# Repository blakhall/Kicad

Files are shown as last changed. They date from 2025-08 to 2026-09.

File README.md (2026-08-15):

# 📝 사내 KiCad 공통 라이브러리 관리 규정 (README)

본 문서는 사내 KiCad(키캐드) 심볼, 풋프린트, 3D 모델 라이브러리의 분류 체계를 표준화하고, 다른 부서 및 외부 참조 라이브러리와 유기적으로 동기화하여 관리하기 위한 표준 규정입니다.

---

## 1. 외부 참조 라이브러리 연동 및 유기적 관리 규정

사내 하드웨어 설계의 통일성과 검증된 회로 자산의 재사용을 위해, 아래의 외부 프로젝트 참조 폴더 내 파일과 이 저장소를 유기적으로 연동하여 관리합니다.

* **연동 및 참조 대상 폴더 경로:**  
  `D:\huni\sw\antigravity\k_dms\storage\archive\Projects\PMO\03_Ref\KiCad`
* **유기적 연동 및 관리 원칙:**
  1. **환경 변수 준수 (`KICAD_GITHUB`):**  
     참조 폴더의 가이드 문서(`KiCad_환경변수_경로설정_가이드.md`)에 따라, 프로젝트 내부 경로 지정 시 특정 개인의 절대 경로 대신 환경 변수 **`${KICAD_GITHUB}`**를 사용하여 치환합니다.
     * 모든 팀원은 본인의 KiCad 경로 구성(Configure Paths)에서 `KICAD_GITHUB` 변수명에 로컬 저장소 경로(`D:\huni\data\github\Kicad`)를 정확히 매핑하여 사용해야 합니다.
  2. **검증 자산의 동기화:**  
     `k_dms` 내의 PMO 관련 검증용 공통 라이브러리 자산에 업데이트가 발생할 경우, 이 저장소의 공통(`common`) 및 범용(`_gen`) 라이브러리에도 즉시 동기화하여 버전의 일관성을 유지합니다.
  3. **회로도 및 풋프린트 경로 치환 규칙:**  
     프로젝트 라이브러리 테이블(`sym-lib-table`, `fp-lib-table`) 등록 시, 환경 변수를 활용하여 아래 예시와 같이 유기적인 상대 경로 매핑을 구현합니다.
     * *올바른 예 (환경 변수 치환):* `(uri "${KICAD_GITHUB}/symbols/common_gen.kicad_sym")`
     * *잘못된 예 (절대 경로 사용 금지):* `(uri "D:/huni/data/github/Kicad/symbols/common_gen.kicad_sym")`

---

## 2. 라이브러리 분류 및 명명 표준 (Library Grouping Rules)

심볼(`symbols/`) 및 풋프린트(`footprints/`) 라이브러리는 무분별한 파일 생성을 방지하고 탐색 효율성을 극대화하기 위해 다음 규칙에 따라 관리합니다.

1. **공통 기본 소자 (`common` 계열):**
   * 저항(R), 콘덴서(C), 인덕터(L), 다이오드, GND 등 모든 보드에서 기본적으로 재사용되는 패시브 및 전원 기본 기호는 `common.kicad_sym` 및 `common.pretty`에만 수록합니다.
2. **기능별 범용 IC 및 소자 (`*_gen` 계열):**
   * 특정 단일 부품이 아니며 광범위하게 쓰이는 기능별 액티브 칩셋들은 접미사 `_gen`이 붙은 카테고리 파일에 병합하여 관리합니다.
   * *예시:* `mcu_gen.kicad_sym` (범용 MCU), `power_gen.kicad_sym` (범용 전원 IC 및 MOSFET), `common_gen.kicad_sym` (범용 아날로그/기초 IC)
3. **단독 부품 라이브러리 파일 생성 지양:**
   * 특정 단일 칩을 위한 개별 라이브러리 파일(예: `CSD17308.kicad_sym` 등)은 무분별한 파일 개수 증가를 유발하므로 원칙적으로 생성을 금지합니다.
   * 단, 핀 수가 100개 이상이거나 구조가 매우 독특한 대형 파워 모듈이나 특정 통신 모듈 등의 특수 부품에 한해서만 독자적인 명명을 예외 허용합니다.

---

---

## 3. 심볼 파라메터 필드 규정 (Symbol Property Fields Rule)

모든 부품 심볼에는 회로도 설계 완료 후 BOM(Bill of Materials) 추출 및 자재 매칭을 위해 아래의 **표준 파라메터 속성 필드**를 필수로 추가해야 합니다.

1. **`Reference` (참조 지정자):**  
   * 부품 카테고리에 맞는 영문 지시자 (예: IC는 `U`, 저항은 `R`, 콘덴서는 `C` 등). 심볼 상단에 표시 (글자 크기 1.27mm).
2. **`Value` (부품 값 / 모델명):**  
   * 실제 부품의 핵심 값 또는 세부 모델명 (예: `10k`, `0.1uF`, `MCP2122T-E/SN`). 심볼 하단에 표시 (글자 크기 1.27mm).
3. **`Footprint` (풋프린트):**  
   * 해당 부품의 PCB 패드 패턴 경로. 필수 지정하되 회로도상에서는 **숨김(Hide)** 처리.
4. **`Datasheet` (데이터시트):**  
   * 해당 부품의 제조사 공식 데이터시트 웹 링크. 필수 지정하되 **숨김(Hide)** 처리.
5. **`Description` (사양 설명):**  
   * 부품의 간략한 기능 및 사양 텍스트. **숨김(Hide)** 처리.
6. **`Manufacturer` (제조업체) [사내 필수]:**  
   * 부품의 공식 제조사 이름 (예: `Microchip Technology`, `Vishay`, `TI` 등). **숨김(Hide)** 처리.
7. **`PartNumber` (제조사 부품 번호 / MPN) [사내 필수]:**  
   * 주문 및 구매를 위한 공식 제조업체 파트넘버 (예: `MCP2122T-E/SN`). **숨김(Hide)** 처리.
8. **`Cost` (단가) [사내 필수]:**  
   * 부품 단가 기입용 빈 필드 (추후 BOM 연동용). **숨김(Hide)** 처리.

## 4. PCB 풋프린트 및 3D 모델(STP) 연동 규정 (Footprint & 3D Model Rules)

새로운 라이브러리를 추가하거나 요청할 때는 회로도 심볼뿐만 아니라 **PCB 풋프린트(.kicad_mod)**와 **3D 모델(.step/.wrl)** 파일이 대칭 구조로 유기적으로 연동되어야 합니다.

### ① 저장 경로 대칭성 준수 (Symmetric Directory Structure)
모든 카테고리는 심볼, 풋프린트, 3D 모델이 동일한 이름의 폴더(카테고리)에 쌍을 이루어 저장되어야 합니다.
* **심볼:** `symbols/<category>.kicad_sym`
* **풋프린트:** `footprints/<category>.pretty/<part_name>.kicad_mod`
* **3D 모델:** `3dmodels/<category>/<part_name>.step` (또는 `.wrl`)
* *예시 (센서 부품 추가 시):*
  * 심볼: `symbols/common_sensor.kicad_sym` 내에 추가
  * 풋프린트: `footprints/common_sensor.pretty/TFBS4650.kicad_mod` 생성
  * 3D 모델: `3dmodels/common_sensor/TFBS4650.step` 저장

### ② 환경 변수(`${KICAD_GITHUB}`)를 통한 3D 모델 경로 설정
풋프린트 파일 내부에서 3D 모델을 참조할 때 특정 로컬 컴퓨터의 절대 경로를 기록하면 협업 시 경로 깨짐이 발생합니다. 반드시 환경 변수를 사용하여 상대 경로로 연결합니다.
* **❌ 잘못된 예 (절대 경로 사용 금지):**  
  `(model "D:/huni/data/github/Kicad/3dmodels/common_sensor/TFBS4650.step" ...)`
* **⭕ 올바른 예 (환경 변수 치환):**  
  `(model "${KICAD_GITHUB}/3dmodels/common_sensor/TFBS4650.step" (at (xyz 0 0 0)) ...)`

### ③ 라이브러리 요청 시 필수 제출 파일
신규 부품 라이브러리 생성을 요청할 때에는 아래 **3종 파일**을 반드시 패키지로 준비하여 저장소의 지정된 카테고리 경로에 배치해야 합니다:
1. **심볼 사양 및 S-expression 정의**
2. **PCB 풋프린트 파일 (`.kicad_mod` 포맷)**
3. **3D 모델 파일 (`.step` 또는 `.wrl` 포맷)**

### ④ 3종 파일 및 데이터시트 도면 교차 검증 절차 (Reviewer Cross-Check)
라이브러리 및 풋프린트 생성 시, 추정치에 의존하지 않고 제조사 **공식 데이터시트 도면(Dimensions & Recommended Layout)**과 **3종 세트 파일** 간의 핀 번호/패드 피치/치수 정합성을 반드시 교차 검증(Cross-Verification)해야 합니다.
* **검토자(Reviewer) 필수 점검 체크리스트:**
  * [ ] 회로도 심볼 핀 번호/핀 이름과 풋프린트 `.kicad_mod` 패드 번호 간의 1:1 매핑 일치 여부 (데이터시트 핀맵 임의 추정 금지)
  * [ ] 풋프린트 추천 레이아웃 패드 크기(Width/Height) 및 피치(Pitch), Y/X축 좌표계 정합성
  * [ ] 3D STEP CAD 바운딩 박스/좌표계 정량 파싱 분석(`scripts/analyze_step_cad.py`)을 통한 패드 상 물리적 안착(Seating), 1번 핀(Pin 1 Dot) 방향 및 회전 각도(Rotation), PCB 패드 표면(Z=0) 들뜸/파묻힘 없는 XYZ 오프셋(Offset) 완전 밀착 정합성 검증 (정식 CAD STEP만 사용)

  * [ ] 풋프린트 내 3D 모델 상대 경로(`${KICAD_GITHUB}`) 연결 및 3종 파일 정상 등록 여부
  * [ ] 파이썬 검증 스크립트(`core/validator.py`) 실행을 통한 100% PASS 검증 수락 여부

### ⑤ 기존 표준 패키지 풋프린트 최우선 재활용 원칙 (Reuse Existing Standard Footprints)
* **범용 표준 패키지 재활용:** JEDEC 및 IPC 표준 규격(예: `Package_QFP:LQFP-48_7x7mm_P0.5mm`, `Package_SO:SOIC-*`, `Package_DFN_QFN:QFN-*` 등)을 사용하는 부품의 경우, 개별 카테고리 폴더에 중복으로 풋프린트를 생성하지 않고 **KiCad 공식 표준 또는 사내 공통 패키지 라이브러리의 검증된 풋프린트를 최우선 재활용**합니다.
* **신규 풋프린트 제작 대상:** 제조사 고유의 비표준 외형 치수, 특수 방열 패드 구조, 독자적 커넥터/모듈 등 기존 표준 라이브러리에 부합하는 풋프린트가 없는 경우에 한해 3종 세트(심볼/풋프린트/3D모델)를 신규 제작합니다.

## 5. Git 버전 관리 및 협업 규칙

* **자동 생성 백업 파일 (.bak) 추적 제외:**
  * KiCad 저장 시 자동으로 생성되는 `.bak` 및 `.kicad_sym.bak` 파일은 로컬 설계자의 PC에만 임시 복구용으로 남겨두고, Git 변경 이력의 충돌 방지를 위해 `.gitignore`에 등록하여 원격 저장소 업로드를 차단합니다.
  * 모든 팀원은 리포지토리에 커밋하기 전 불필요하게 추적 중인 백업 파일이 존재하지 않는지 점검합니다.

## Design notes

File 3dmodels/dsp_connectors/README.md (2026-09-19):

# dsp_connectors library

Prepared 2026-09-11 for the DSP module. Two exact part metadata symbols and
two drawing-derived footprints: FTSH-122-03-L-DV and CLP-122-02-L-D.
Electrical symbol graphics derive from KiCad Connector_Generic:Conn_02x22_Odd_Even.
Original KiCad libraries are unmodified; retain the KiCad library attribution
and license/exception when redistributing derived symbols.

Directory layout follows the corporate library convention. Published model
links use `${KICAD_GITHUB}/3dmodels/dsp_connectors/`. The project has a snapshot
of the header symbol. Cost is deliberately empty, not zero.

The STEP files are generated nominal envelopes, NOT Samtec-supplied CAD.
Housing/terminal bounds and all 44 contact axes follow the drawing; molded
reliefs, bent lead radii and internal socket springs are simplified. Red pin 1
in preview images is an annotation and not a claim about actual contact color.
STEP geometry is in mm, Z=0 on the soldering plane, no model transform required.

Manufacturer sources:

- FTSH product drawing Rev FX: https://suddendocs.samtec.com/prints/ftsh-1xx-xx-xxx-dv-xxx-xxx-x-xx-mkt.pdf
- FTSH PCB/stencil Rev H: https://suddendocs.samtec.com/prints/ftsh-1xx-xx-xxx-dv-xxx-footprint.pdf
- CLP product drawing Rev DH: https://suddendocs.samtec.com/prints/clp-1xx-xx-xxx-d-xx-xx-xx-mkt.pdf
- CLP PCB/stencil Rev W: https://suddendocs.samtec.com/prints/clp-1xx-xx-xxx-d-xx-footprint.pdf

Use the drawing's primary inch dimensions converted to mm. Header pads
0.7366 x 2.794 at Y=+/-2.032; socket pads 0.7366 x 1.4732 at Y=+/-1.6129.
Pitch is 1.27 mm. No -A alignment holes, -BE entry holes or latch features.
In component-side views, pin 1 is lower left on the header and lower right on
the socket. Do not mirror a footprint manually to compensate for bottom-side
placement; KiCad handles the layer flip. Check actual board-coordinate mating.

Nominal PCB-surface spacing is 5.207 mm from the two seating heights.
This is not a guaranteed spacer dimension. Stencil recommendation is 0.152 mm
in the source documents; final solder mask, stencil, process and mechanical
retention require assembly review. No production board layout is included.

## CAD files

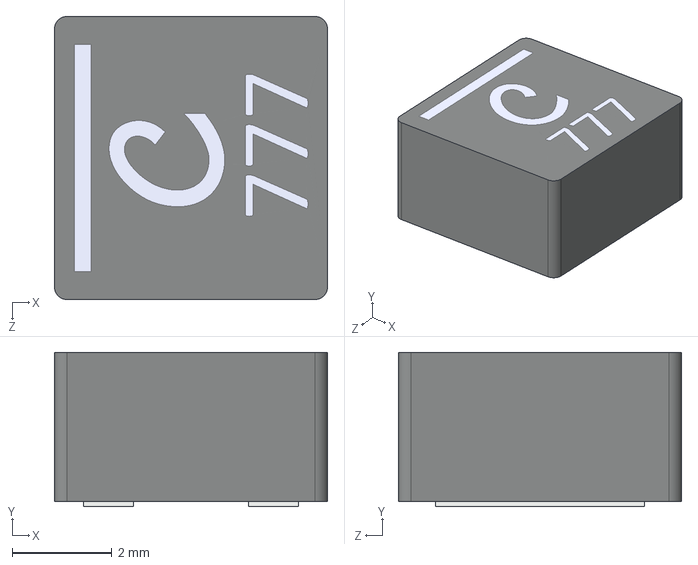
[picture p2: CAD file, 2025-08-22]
3dmodels/by_manufacturer/coilcraft/Coilcraft-XFL5030.step
5.48 x 3.10 x 5.68 mm

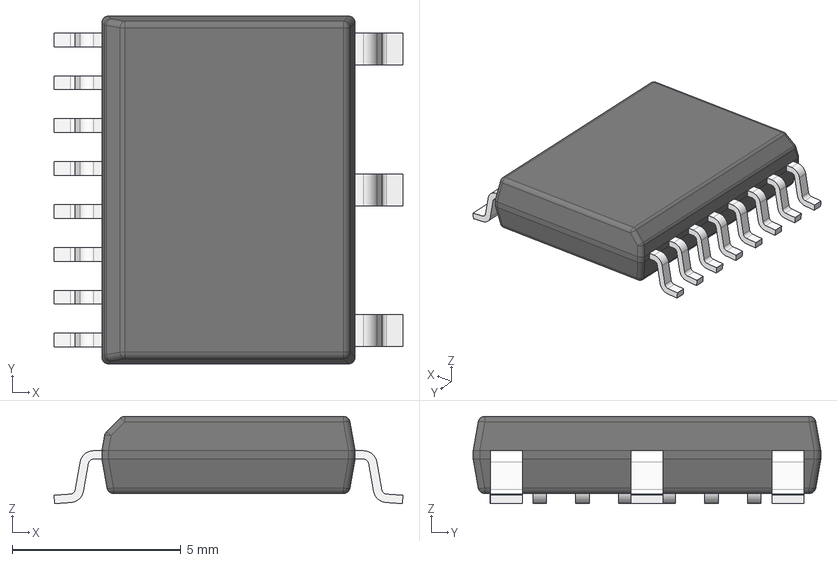
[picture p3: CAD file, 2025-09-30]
3dmodels/by_manufacturer/ti/TPSI2140QDWQRQ1.stp
10.3 x 10.3 x 2.59 mm
BODY-SOIC
LEAD x 8
LEAD-WIDE x 3

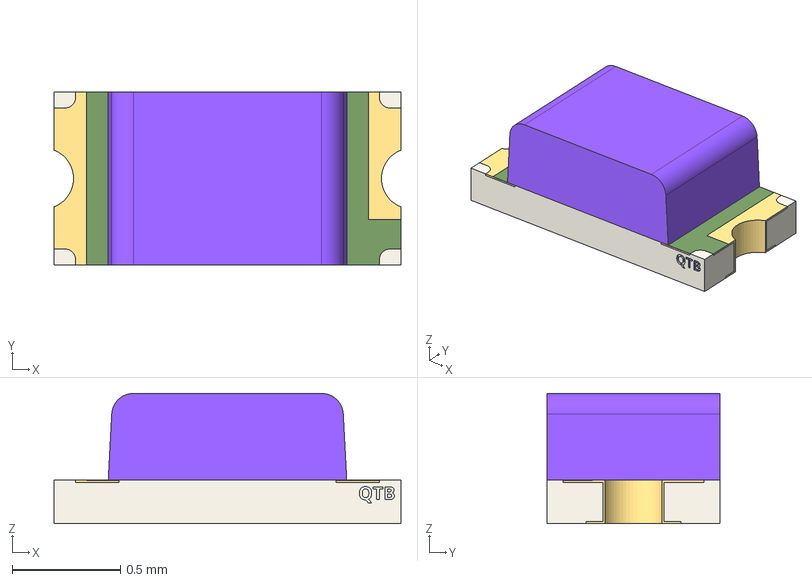
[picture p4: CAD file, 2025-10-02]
3dmodels/common/led/led-1608-blue.step
1.60 x 0.8 x 0.6 mm
Pattern, Bottom
Resin
Pattern, Top Right
Pad, Left
Pattern, Top Left
Substrate
Pad, Right

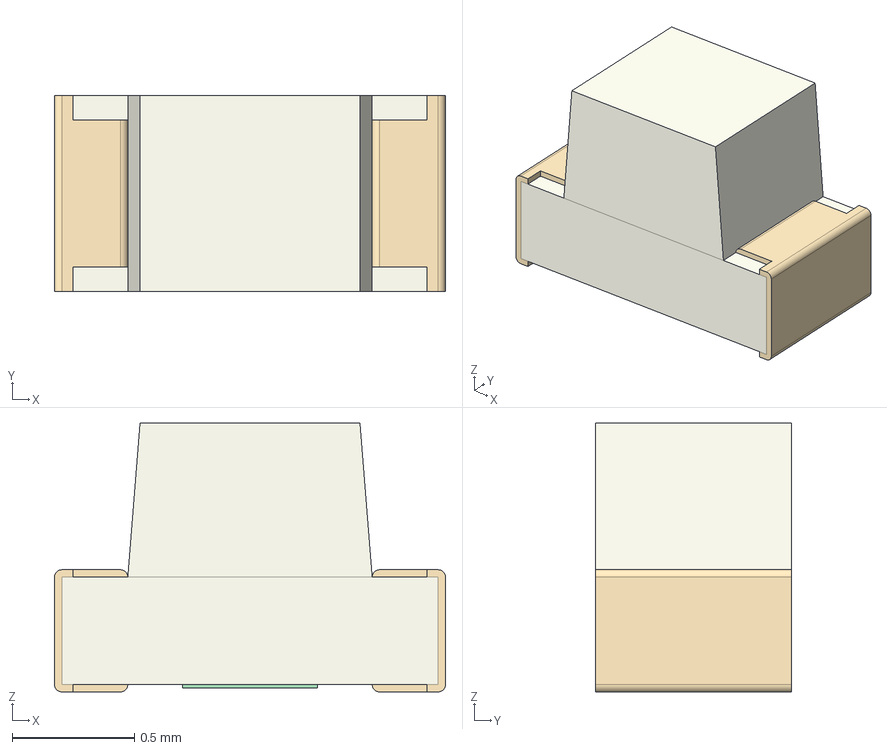
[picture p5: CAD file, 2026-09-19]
3dmodels/common/LED_0603_1608Metric.step
1.60 x 0.8 x 1.10 mm

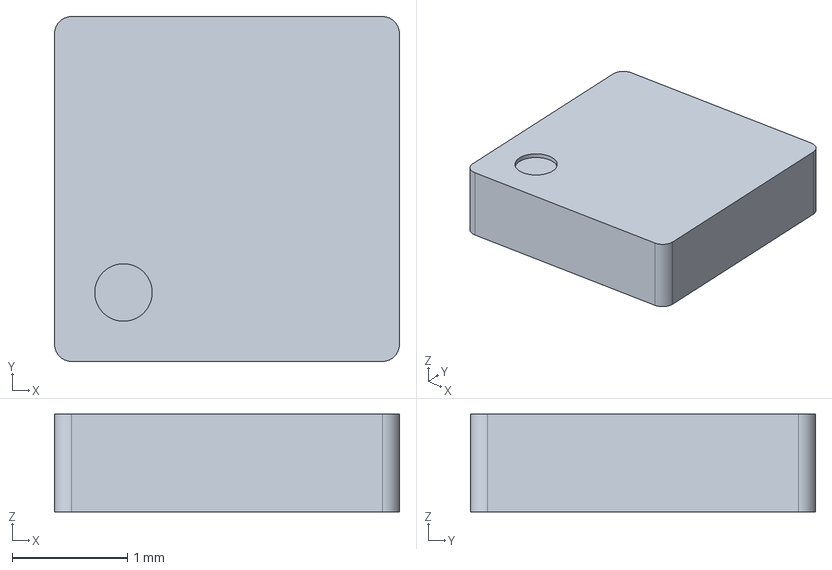
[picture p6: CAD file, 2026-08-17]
3dmodels/common_gen/TJA1044TK-3.step
3.00 x 3.00 x 0.85 mm

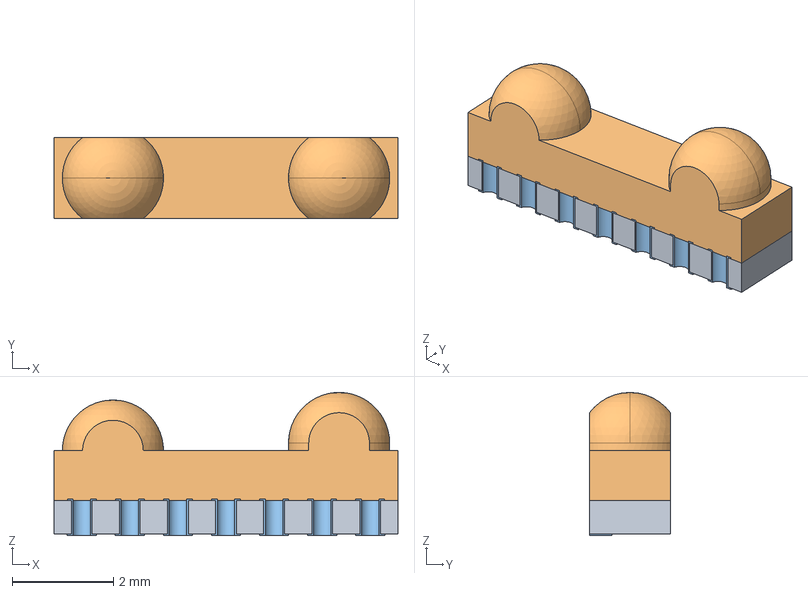
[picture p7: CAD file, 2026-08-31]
3dmodels/common_sensor/TFBS4650.stp
6.80 x 1.60 x 2.83 mm
PLATINE
EPOXY
KONTAKT x 7

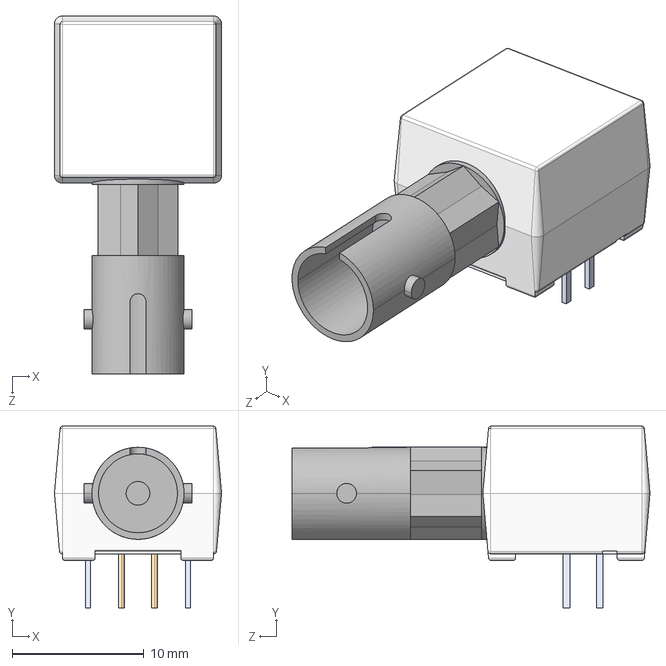
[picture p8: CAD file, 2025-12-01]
3dmodels/connectors/optic/HFBR-X41XT.step
12.7 x 13.8 x 27.2 mm

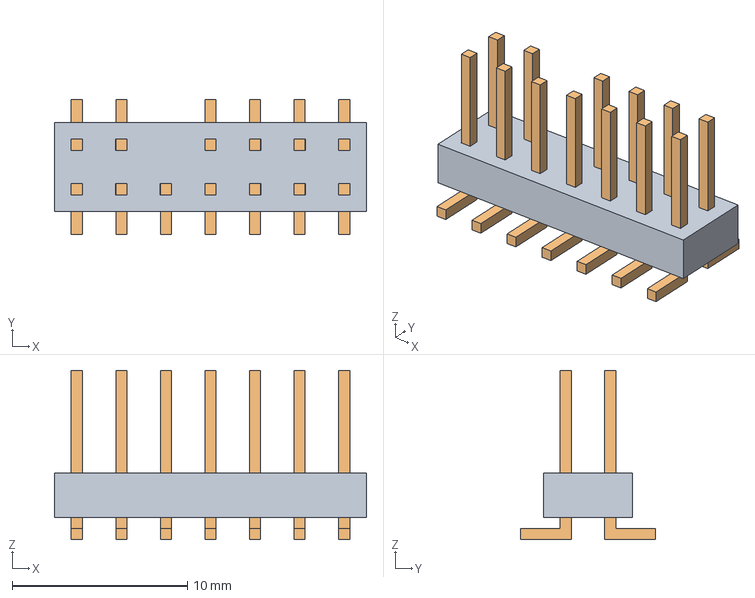
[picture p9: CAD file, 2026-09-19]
3dmodels/connectors/TSM-107-01-L-DV-006.step
17.8 x 7.70 x 9.65 mm

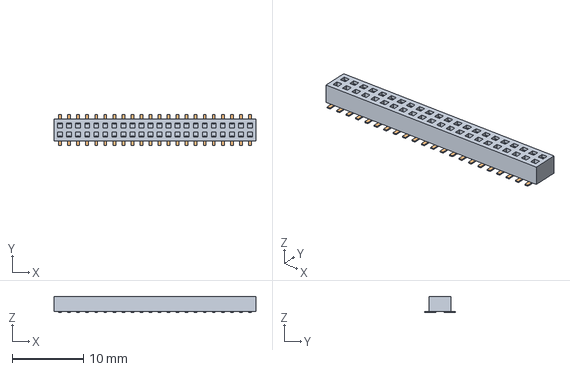
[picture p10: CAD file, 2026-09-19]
3dmodels/dsp_connectors/CLP-122-02-L-D.step
28.4 x 4.32 x 2.29 mm

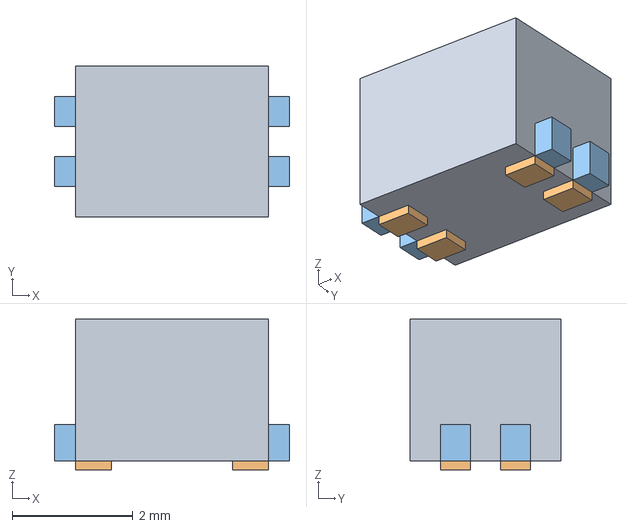
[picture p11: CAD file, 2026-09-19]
3dmodels/dsp_emc/ACT1210D-510-2P-TL00.step
3.90 x 2.50 x 2.50 mm

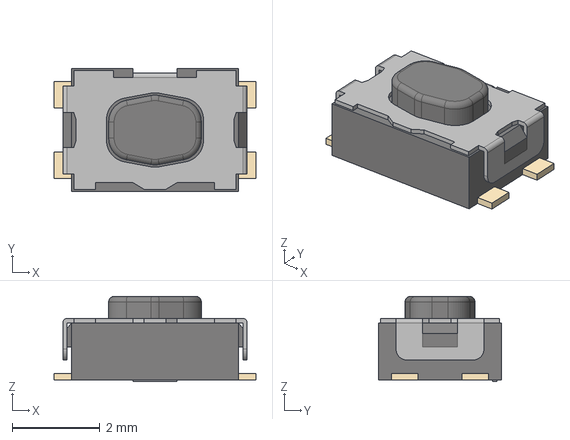
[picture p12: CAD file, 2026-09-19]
3dmodels/electrical/SW_Push_1P1T-SH_NO_CK_KMR2xxG.step
4.60 x 2.80 x 1.94 mm

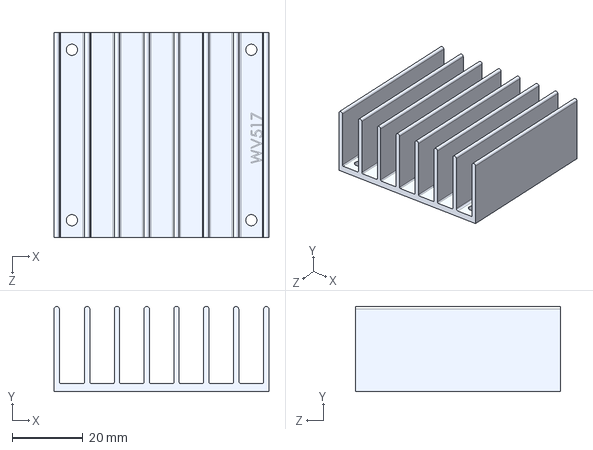
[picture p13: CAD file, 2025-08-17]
3dmodels/etc/517-95AB%20HEATSINK%20BXB50%2C75%2C100%2C150.95-HRZ.step
60.9 x 24.2 x 57.9 mm

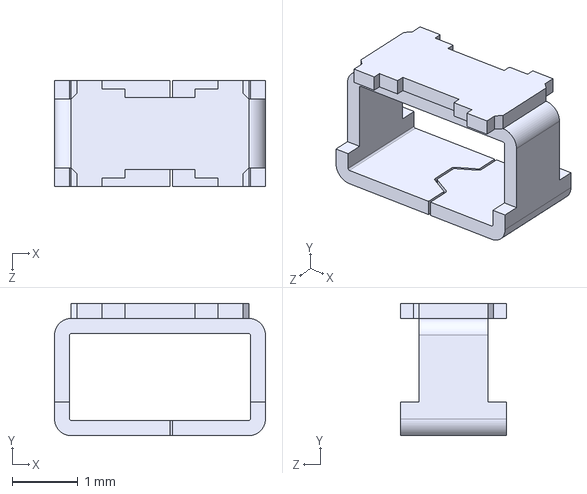
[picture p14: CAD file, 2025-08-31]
3dmodels/etc/testpoints/RCWCTE.STEP
3.20 x 2.01 x 1.60 mm

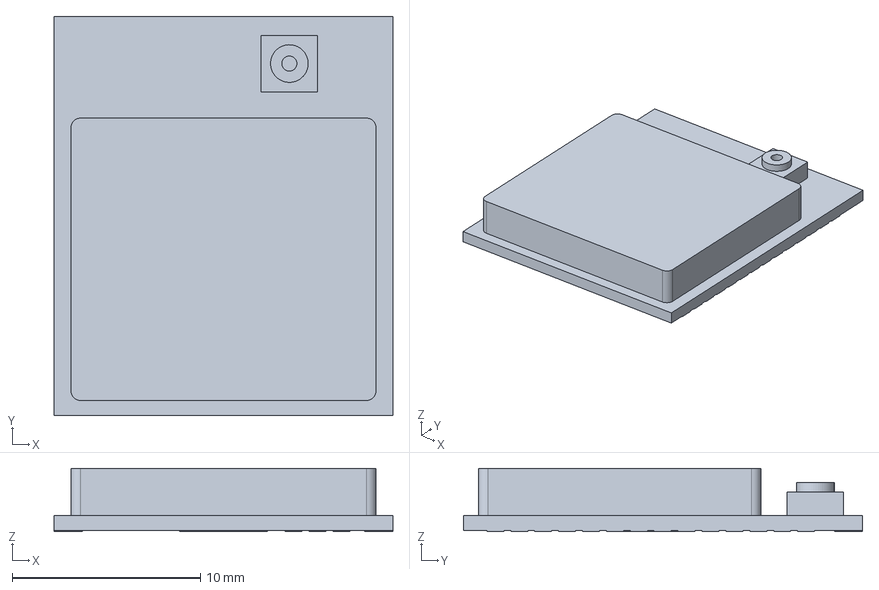
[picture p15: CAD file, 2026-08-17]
3dmodels/mcu_gen/ESP32-C5-WROOM-1U.step
18.0 x 21.2 x 3.35 mm

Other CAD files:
3dmodels/power_dcdc/SY8088AAC.step
3dmodels/so_gen/SOIC-6-Stretched_DWY_TI.step
3dmodels/wpt_driver/SOIC-16_3.9x9.9mm_P1.27mm.step
3dmodels/wpt_magnetics/SCF29XV-200-2R0A011JV.step
3dmodels/by_manufacturer/maxim/MAX20801TPBA+.stp
3dmodels/common/7448052502.step
3dmodels/common/B32923C3105K000.step
3dmodels/common/B57236S0500M051.step
3dmodels/common/B72225S4271K101.step
3dmodels/common/B82787C_Series.stp
3dmodels/common/CD-HD2004L.step
3dmodels/common/Celem_CSM_IPT.step
3dmodels/common/Celem_CSM_Nano.step
3dmodels/common/Converter_DCDC_Mornsun_QAxx3C-R3S_THT.step
3dmodels/common/DE2E3SA222MA3BY02F.step
3dmodels/common/DE2E3SA472MA3BY02F.step
3dmodels/common/D_DO-216AA.step
3dmodels/common/Filter_DataLine_Coilcraft_PDLF_8SMD.step
3dmodels/common/Infineon_PG-DSO-14_2EDB8259Y.step
3dmodels/common/Keystone_8174.step
3dmodels/common/R76PR368050H4J.step
3dmodels/common/SC-07-10J.step
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

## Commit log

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2025-07-03 adder lib..
    [SOT-227.stp, power_module_62mm.stp]
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2026-07-08 docs: add PCB footprint and 3D STP model linkage rules to README
2026-07-08 Add Vishay TFBS4650-TT3 IrDA transceiver symbol, footprint, and 3D model
    [TFBS4650.stp]
2026-07-09 Add JST S4B-PH-K-S 4-pin right-angle connector symbol, footprint, and 3D model
    [S4B-PH-K-S.step]
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2026-07-17 feat(power_dcdc): Add Mornsun F0515XT-1WR3 & RECOM R1SE-0515 1W DC-DC converters with 3D STEP models and update reviewer rules
    [Converter_DCDC_Mornsun_XT-1WR3_SMD.step, Converter_DCDC_RECOM_R1SE_SMD.step]
2026-07-20 feat(power_gen): Add AIF04ZPFC-01NTL PFC module symbol, footprint and 3D STEP model
    [Converter_PFC_Artesyn_AIF04ZPFC-01NTL.step, IC_IS31CG5317-LQLS3_LQFP80.step]
2026-07-20 fix(3dmodels): Fix STEP header representation context for OpenCASCADE parser compatibility
    [Converter_DCDC_Mornsun_XT-1WR3_SMD.step, Converter_DCDC_RECOM_R1SE_SMD.step, Converter_PFC_Artesyn_AIF04ZPFC-01NTL.step]
2026-07-20 fix(3dmodels): Replace handcrafted STEP files with CadQuery OpenCASCADE CAD STEP models
    [Converter_DCDC_Mornsun_XT-1WR3_SMD.step, Converter_DCDC_RECOM_R1SE_SMD.step, Converter_PFC_Artesyn_AIF04ZPFC-01NTL.step]
2026-07-20 fix(3dmodels): Align AIF04ZPFC-01NTL 3D signal header pins Y-coordinate with footprint pads and datasheet
    [Converter_PFC_Artesyn_AIF04ZPFC-01NTL.step]
2026-07-20 fix(library): Update AIF04ZPFC-01NTL 3D STEP and footprint to match official Artesyn mechanical drawing (2x8 header, left=OUTPUT, right=L1/L2 AC INPUT)
    [Converter_PFC_Artesyn_AIF04ZPFC-01NTL.step]
2026-07-23 feat(connectors): add JST PH series 2~6 pin side/top entry libraries (S2B-S6B, B2B-B6B)
    [B2B-PH-K-S.step, B3B-PH-K-S.step, B4B-PH-K-S.step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]
2026-08-02 feat: Add UCC23313BDWY and ACS37030 current sensor libraries, update SKMW20/THN-20 footprints and 3D STEP paths
    [ACS37030LLZATR-065B3.step, Converter_DCDC_MeanWell_SKMW20G-12.step, Converter_DCDC_TRACO_THN-20UIR.step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]
2026-08-02 feat: Add TI UCC14141QDWNRQ1 isolated DC/DC power module symbol, 36-pin DWN footprint, and 3D STEP model
    [SOIC-36W_7.5x12.8mm_P0.65mm_DWN_TI.step]
2026-08-02 fix(symbol): Stack and hide duplicate power pins for UCC14141QDWNRQ1 to prevent schematic text overflow
2026-08-02 fix(symbol): Add pin-level (hide yes) to all stacked duplicate pins for UCC14141QDWNRQ1
2026-08-02 feat(symbol): Add direct ACS37030 symbol name and search keywords to common_sensor.kicad_sym
2026-08-02 fix(symbol): Fix S-expression syntax error in common_sensor.kicad_sym so KiCad 10 parses ACS37030 cleanly
2026-08-15 feat(mcu): Add STM32C542CCT6 symbol and standard footprint reuse rule
    - Add STM32C542CCT6 symbol to mcu_gen.kicad_sym with all 48 pins, alternate functions, and 8 mandatory company properties
    - Resolve pin overlaps (PB9, PB10, VSS) with unique coordinates
    - Map footprint to KiCad standard Package_QFP:LQFP-48_7x7mm_P0.5mm
    - Add standard footprint reuse rule to README.md
    - Add Molex Sabre 431601302 2-pin connector 3-piece library set
    [0431601302.step]
2026-08-17 feat: Add libraries for ESP32-C5-WROOM-1U, SMAW250, ECMF02-2AMX6, TJA1051TK-3, CLP-104-02, USB4105, LD39050
    - ESP32-C5-WROOM-1U: Wi-Fi 6 / BT5 / 802.15.4 module with top RF pads (30: GND, 31: ANT2, 32: GND), 3D model, symbol, and footprint
    - SMAW250-02~06: Yeonho 2.50mm Right-Angle Wafer footprints with 180-deg rotation and exact 3D alignment
    - ECMF02-2AMX6: uQFN-6L common mode filter with ESD protection
    - TJA1051TK/3 & TJA1044TK/3: HVSON-8 CAN FD transceivers with precision 3D CAD models
    - Samtec CLP-104-02-F-D-TR: 2x04 1.27mm SMD socket strip
    - GCT USB4105-GF-A: USB Type-C receptacle with 3D model and footprint
    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
    [B82787C_Series.stp, CLP-104-02-F-D-TR.stp, ECMF02-2AMX6.step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]
2026-08-30 fix(symbols): restore missing PartNumber property header in common_gen.kicad_sym
2026-08-31 feat(sensor): add TFBS4650-TR1 and update TFBS4650 footprints & 3D model
    [TFBS4650.stp]
2026-09-04 feat(etc, power_gen): add silkscreen logos, board marking info, and RAK0009A package
    [Texas_RAK0009A_WQFN-HR-9_2.5x2.0mm.step]
2026-09-08 feat(lib): add T9AS5D12-5 relay, SC-07-10J choke, and update AIF04ZPFC-01NTL
    - Add TE Connectivity T9AS5D12-5 SPDT 30A power relay (symbol, footprint, 3D model)
    - Add KEMET SC-07-10J common mode choke with official STEP model
    - Update AIF04ZPFC-01NTL symbol pin types to passive to prevent ERC errors
    - Add passive components (Murata DE2E3, TDK B32923, EPCOS S236/S25K, Wurth 7448052502) footprints and 3D models
    [7448052502.step, AIF04ZPFC-01NTL.step, B32923C3105K000.step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]
2026-09-08 fix(relay): replace T9AS5D12-5 with official TE 3D model and calibrate footprint outline
    [T9AS5D12-5.step]
2026-09-08 fix(relay): enlarge T9AS5D12-5 power contact pad holes to 2.0mm for 30A rectangular pins
2026-09-08 fix(choke): update SC-30-D010 with official KEMET 3D model and align footprint pin 1-4 polarity
    [SC-30-D010.step]
2026-09-08 feat(choke): add KEMET SCF29XV-150-1R7A015JV automotive common mode choke
    [SCF29XV-150-1R7A015JV.step]
2026-09-08 feat(cap): add KEMET R76PR368050H4J 0.68uF 630V film capacitor
    [R76PR368050H4J.step]
2026-09-08 feat(connector): add Keystone 8174 10-32 heavy duty PC screw terminal
    [Keystone_8174.step]
2026-09-08 fix(diode): standardize Bourns CD-HD2004 bridge rectifier library, footprint, and 3D model
    - Symbol (common:CD-HD2004):
    - Corrected Footprint link to 'common:CD-HD2004L'
    - Updated Datasheet URL to official Bourns CD-HD2x(L) datasheet
    - Set Manufacturer='Bourns', PartNumber='CD-HD2004', and comprehensive description
    - Verified pin mappings: Pin 1 (+), Pin 2 (~), Pin 3 (~), Pin 4 (-) exactly matching Bourns specification
    - Footprint (common:CD-HD2004L):
    - Fixed typo in property 'Part Numer' -> 'Part Number'
    - Added Datasheet, Description, and Manufacturer properties
    - Updated 3D model path to '\/3dmodels/common/CD-HD2004L.step' with zero offset and rotation
    - Re-verified Pad 1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
    [CD-HD2004.stp, CD-HD2004L.step]
2026-09-08 feat(transformer): add Pulse PAS6322.100NLT 50A 1:100 SMT current sense transformer
    - Symbol (common:PAS6322.100NLT):
    - Primary: Pin 1 (PRI 1), Pin 2 (PRI 2 with dot)
    - Secondary: Pin 6 (SEC 1 with dot), Pin 5 (SEC 2)
    - Mechanical/NC: Pin 3, Pin 4 (hidden passive for full footprint pin matching)
    - Bound to 'common:Transformer_CurrentSense_Pulse_PAS6322' footprint
    - Complete metadata (Manufacturer='Pulse Electronics', PartNumber='PAS6322.100NLT', Mouser datasheet link)
    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
    [Transformer_CurrentSense_Pulse_PAS6322.step]
2026-09-09 feat(lib): add Infineon 2EDB8259Y dual-channel isolated gate driver
    [Infineon_PG-DSO-14_2EDB8259Y.step]
2026-09-09 feat(lib): align 3D Pin 1 dot and add 2EDB9259F, 2EDB9259Y, 2EDB8259F symbols
    [Infineon_PG-DSO-14_2EDB8259Y.step]
2026-09-09 feat(lib): add TI UCC21551x dual-channel isolated gate driver (DWK SOIC-14)
    [SOIC-14_7.5x10.3mm_P1.27mm_TI_DWK0014A.step]
2026-09-09 fix(symbols): fix KiCad 10 syntax errors in UCC21551 and 2EDB8259Y
2026-09-09 feat(lib): add onsemi MBRM130LT1G Schottky diode and DO-216AA (POWERMITE) footprint/3D model
    [D_DO-216AA.step]
2026-09-09 fix(symbols): correct UVLO voltage mapping for UCC21551A/B/C/D (A=5V, B=8V, C=12V, D=17V)
2026-09-09 feat(lib): add Mornsun QA053C-1803R3S isolated DC-DC converter for SiC gate driver
    [Converter_DCDC_Mornsun_QAxx3C-R3S_THT.step]
2026-09-09 feat(lib): add Coilcraft PDLF4500LC 4-line SMT data line EMI filter
    [Filter_DataLine_Coilcraft_PDLF_8SMD.step]
2026-09-09 fix(footprint): align KEMET SCF29XV choke 3d model offset and footprint
    [SCF29XV-150-1R7A015JV.step]
2026-09-09 fix(symbol): hide pin names in PDLF4500LC common mode choke symbol
2026-09-17 feat(lib): add Celem CSM IPT & CSM Nano conduction-cooled capacitors
    [Celem_CSM_IPT.step, Celem_CSM_Nano.step]
2026-09-19 feat(lib): add WPT power-stage sensing and gate-drive components
    Register WPT current sensing, gate bias, supervisory logic, relays,
    PFC inductors, output common-mode choke and 30 W supply assets.
    Include DC-link capacitor and relay footprints and portable ACS model path.
    Preserve concurrent DSP and PoC additions as unstaged changes.
    Preserve supplied STEP model contents, including existing whitespace.
    Library assets retain review status; this is not hardware qualification.
    [C_0603_1608Metric.step, R_0603_1608Metric.step, R_1206_3216Metric.step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]
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2026-09-19 feat(lib): register shared DSP components and BOM metadata
    [FTR-110-51-L-D-06.step, FTSH-104-03-L-DV.step, LED_0603_1608Metric.step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]
2026-09-19 feat(lib): add SN74LVC1G08, SN74LVC1G17, NCP4306, ISO7710, and BAT54WS components
    - Add SN74LVC1G08DBVR (AND gate) and SN74LVC1G17DBVR (Schmitt buffer) to common_gen.kicad_sym
    - Add NCP4306 SR driver controller to common_gen.kicad_sym
    - Add ISO7710FDR (default low) and ISO7710DR (default high) isolators to common_gen.kicad_sym
    - Add BAT54WS-7-F Schottky diode to common.kicad_sym with Diode_SMD:D_SOD-323 footprint
    - Enforce mandatory 8-field property rules and validation with zero errors
2026-09-19 feat(dsp): register DSP interface connectors and EMC filter footprints and 3D models
    [ACT1210D-510-2P-TL00.step, CLP-122-02-L-D.step, FTSH-122-03-L-DV.step]
2026-09-19 fix(footprint): use \ variable for PDLF filter 3D model paths
2026-09-19 fix(symbols): standardize Cost fields, properties, and KiCad 10 format in sensor, dcdc, mcu, and WPO libraries

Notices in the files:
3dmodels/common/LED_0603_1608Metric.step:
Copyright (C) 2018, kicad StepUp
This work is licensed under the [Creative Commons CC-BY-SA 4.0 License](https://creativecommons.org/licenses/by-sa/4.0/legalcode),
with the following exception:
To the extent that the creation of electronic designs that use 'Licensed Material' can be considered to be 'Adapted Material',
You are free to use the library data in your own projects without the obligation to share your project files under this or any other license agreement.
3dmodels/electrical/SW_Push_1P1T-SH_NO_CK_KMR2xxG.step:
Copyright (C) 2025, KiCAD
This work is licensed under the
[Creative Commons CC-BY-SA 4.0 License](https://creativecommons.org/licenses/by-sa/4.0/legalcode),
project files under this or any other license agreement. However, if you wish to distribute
